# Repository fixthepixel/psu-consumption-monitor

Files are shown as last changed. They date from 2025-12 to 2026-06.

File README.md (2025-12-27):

# PSU Consumption Monitor

High-side current and power monitoring board for **ATX power supplies**.  
This project allows measuring real-time **current, voltage, and power consumption**
on major ATX rails for diagnostics, testing, and educational purposes.

Created and documented by **FixThePixel**.

---

## ✨ Features

- High-side current sensing using precision shunt resistors
- Multi-rail monitoring:
  - +12 V
  - +5 V
  - +3.3 V
  - +5 VSB
- Bus voltage and current measurement via **INA3221**
- Inline ATX connector design
- MicroPython-based firmware
- Project-local KiCad symbols and footprints
- Clean, GitHub-friendly project structure

---

## 📐 Measurements

Per-rail power is calculated as:

```
Power (W) = Voltage (V) × Current (A)
```

Total system power can be derived by summing all monitored rails.

---

## 🧰 Tools & Requirements

### Hardware / CAD

- **KiCad 9.x** (tested)
- Standard KiCad libraries (symbols, footprints, 3D models)

---

## 🧩 3D Models

This repository **does not include third-party 3D models**.

- Standard KiCad 3D models are referenced via `${KICAD*_3DMODEL_DIR}`
- Third-party 3D models shown in videos are **not bundled**
- Optional model links may be provided separately

---

## 🧪 Fabrication (Gerbers)

Generated Gerber files are included for **non-commercial manufacturing only**.

See `gerber/README.md` for fabrication-specific notes and licensing.

---

## 🔌 Firmware

The `/firmware` directory contains MicroPython firmware for the monitor.

### Firmware Installation Guide

1.  **Board**
   
    MicroPython firmware must be installed on the target board (RP2040).

2.  **Installation**
   
    Copy all `*.py` files from `/firmware` directory into the root directory of the MicroPython device.

3.  **Third-party dependencies**
   
    The firmware depends on the ILI9341 display driver and font files from:

    - `https://github.com/jeffmer/micropython-ili9341`

    Required files:
      - ili934xnew.py
      - glcdfont.py
      - tt14.py
      - tt24.py

    These files are used unmodified and retain their original MIT license.
    They must also be copied to the root directory of the MicroPython device.

---

## 📜 License

This project is licensed under:

**Creative Commons Attribution–NonCommercial 4.0 International (CC BY-NC 4.0)**

Commercial use, manufacturing, or sale is **not permitted** without explicit permission.

https://creativecommons.org/licenses/by-nc/4.0/

---

## ⚠️ Disclaimer

This project is intended for **development, diagnostics, and educational use**.

Working with ATX power supplies involves **high current and potentially hazardous voltages**.
Use at your own risk.

---

## 👤 Author

**FixThePixel**  
YouTube: https://www.youtube.com/@FixThePixel

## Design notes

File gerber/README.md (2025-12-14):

# Gerber Fabrication Files

This directory contains **generated Gerber files** for the
**PSU Consumption Monitor** PCB.

These files are provided for convenience to allow users to
manufacture the board without modifying the KiCad project.

---

## ⚠️ Important Notes

- The **KiCad schematic and PCB files** are the authoritative source.
- Gerber files are **derived artifacts** and may become outdated.
- Always review the files in a Gerber viewer before ordering PCBs.

---

## 📐 Board Information

- Layer count: 4
- Copper layers: F_Cu / In1_Cu / In2_Cu / B_Cu
- Separate drill files for PTH and NPTH
- Includes modern `.gbrjob` file

---

## 📜 License

These Gerber files are licensed under:

**Creative Commons Attribution–NonCommercial 4.0 International  
(CC BY-NC 4.0)**

### You MAY:
- Manufacture boards for **personal or educational use**
- Modify the design for **non-commercial purposes**
- Share the files with proper attribution

### You MAY NOT:
- Sell PCBs or assembled boards
- Manufacture for commercial purposes
- Use the design in commercial products
- Offer paid manufacturing or services using these files

Commercial use requires **explicit written permission**
from the author.

License text:
https://creativecommons.org/licenses/by-nc/4.0/

---

## 👤 Attribution

© 2025 **FixThePixel**

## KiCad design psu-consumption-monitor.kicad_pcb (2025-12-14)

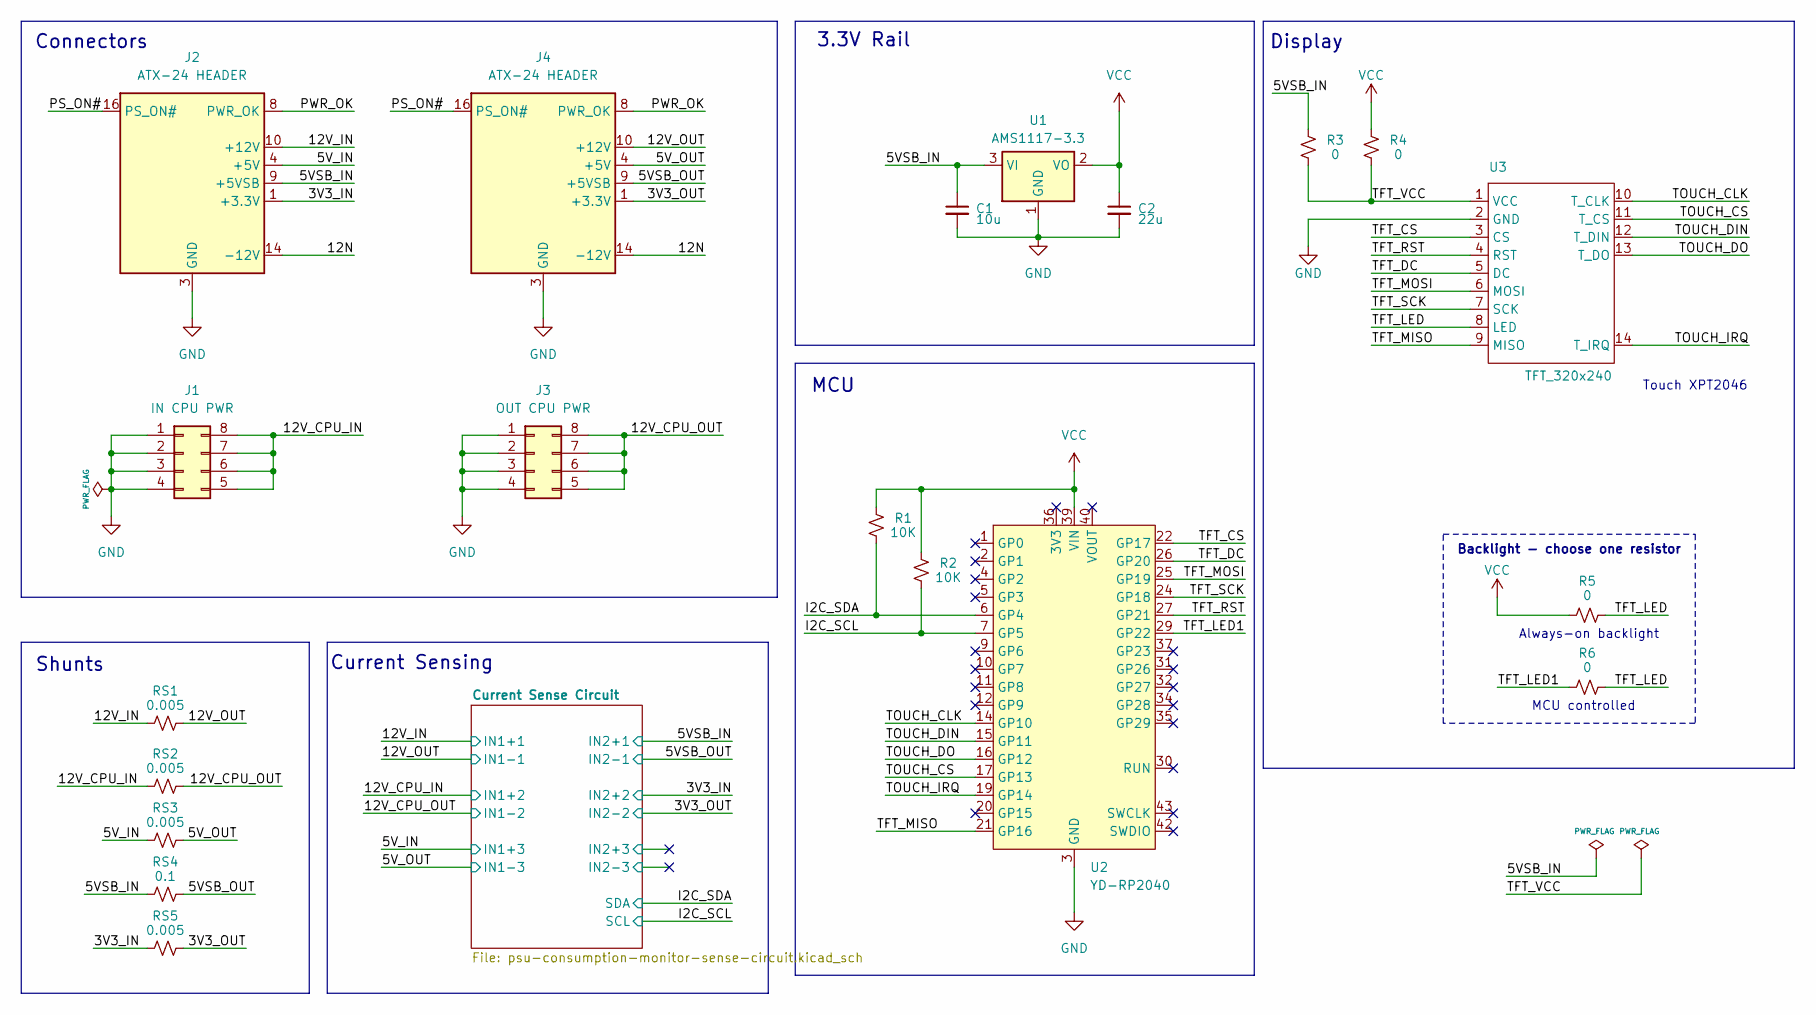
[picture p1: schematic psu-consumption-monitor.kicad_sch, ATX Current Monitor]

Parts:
C1: 10u; C_1206_3216Metric
C2: 22u; C_1206_3216Metric
J1: IN CPU PWR; Molex_Mini-Fit_Jr_5566-08A_2x04_P4.20mm_Vertical
J2, J4: ATX-24 HEADER; ATX-24-HEADER-HORIZONTAL
J3: OUT CPU PWR; Molex_Mini-Fit_Jr_5566-08A_2x04_P4.20mm_Vertical
R1, R2: 10K; R_0805_2012Metric
R3, R4, R5, R6: 0; R_0603_1608Metric
RS1, RS2, RS3, RS5: 0.005; R_2512_6332Metric
RS4: 0.1; R_2512_6332Metric
U1: AMS1117-3.3; SOT-223-3_TabPin2
U2: YD-RP2040
U3: TFT_320x240; TFT-320x240

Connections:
/3V3_IN: J2.1 (+3.3V), J2.2 (+3.3V), J2.12 (+3.3V), J2.13 (+3.3V), RS5.1; also elsewhere on the board
/3V3_OUT: J4.1 (+3.3V), J4.2 (+3.3V), J4.12 (+3.3V), J4.13 (+3.3V), RS5.2; also elsewhere on the board
/5VSB_IN: C1.1, J2.9 (+5VSB), R3.2, RS4.1, U1.3 (VI); also elsewhere on the board
/5VSB_OUT: J4.9 (+5VSB), RS4.2; also elsewhere on the board
/5V_IN: J2.4 (+5V), J2.6 (+5V), J2.21 (+5V), J2.22 (+5V), J2.23 (+5V), RS3.1; also elsewhere on the board
/5V_OUT: J4.4 (+5V), J4.6 (+5V), J4.21 (+5V), J4.22 (+5V), J4.23 (+5V), RS3.2; also elsewhere on the board
/12N: J2.14 (-12V), J4.14 (-12V)
/12V_CPU_IN: J1.5, J1.6, J1.7, J1.8, RS2.1; also elsewhere on the board
/12V_CPU_OUT: J3.5, J3.6, J3.7, J3.8, RS2.2; also elsewhere on the board
/12V_IN: J2.10 (+12V), J2.11 (+12V), RS1.1; also elsewhere on the board
/12V_OUT: J4.10 (+12V), J4.11 (+12V), RS1.2; also elsewhere on the board
/I2C_SCL: R2.1, U2.7 (GP5); also elsewhere on the board
/I2C_SDA: R1.1, U2.6 (GP4); also elsewhere on the board
/PS_ON#: J2.16 (PS_ON#), J4.16 (PS_ON#)
/PWR_OK: J2.8 (PWR_OK), J4.8 (PWR_OK)
/TFT_CS: U2.22 (GP17), U3.3 (CS)
/TFT_DC: U2.26 (GP20), U3.5 (DC)
/TFT_LED: R5.1, R6.1, U3.8 (LED)
/TFT_LED1: R6.2, U2.29 (GP22)
/TFT_MISO: U2.21 (GP16), U3.9 (MISO)
/TFT_MOSI: U2.25 (GP19), U3.6 (MOSI)
/TFT_RST: U2.27 (GP21), U3.4 (RST)
/TFT_SCK: U2.24 (GP18), U3.7 (SCK)
/TFT_VCC: R3.1, R4.1, U3.1 (VCC)
/TOUCH_CLK: U2.14 (GP10), U3.10 (T_CLK)
/TOUCH_CS: U2.17 (GP13), U3.11 (T_CS)
/TOUCH_DIN: U2.15 (GP11), U3.12 (T_DIN)
/TOUCH_DO: U2.16 (GP12), U3.13 (T_DO)
/TOUCH_IRQ: U2.19 (GP14), U3.14 (T_IRQ)
GND: C1.2, C2.2, J1.1, J1.2, J1.3, J1.4, J2.3 (GND), J2.5 (GND), J2.7 (GND), J2.15 (GND), J2.17 (GND), J2.18 (GND), J2.19 (GND), J2.24 (GND), J3.1, J3.2, J3.3, J3.4, J4.3 (GND), J4.5 (GND), J4.7 (GND), J4.15 (GND), J4.17 (GND), J4.18 (GND), J4.19 (GND), J4.24 (GND), U1.1 (GND), U2.3 (GND), U2.8 (GND), U2.13 (GND), U2.18 (GND), U2.23 (GND), U2.28 (GND), U2.33 (GND), U2.38 (GND), U2.44 (GND), U3.2 (GND); also elsewhere on the board
VCC: C2.1, R1.2, R2.2, R4.2, R5.2, U1.2 (VO), U2.39 (VIN); also elsewhere on the board

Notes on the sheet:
Current Sensing
Touch XPT2046
Shunts
3.3V Rail
Display
Backlight - choose one resistor
MCU controlled
Always-on backlight
Connectors
MCU

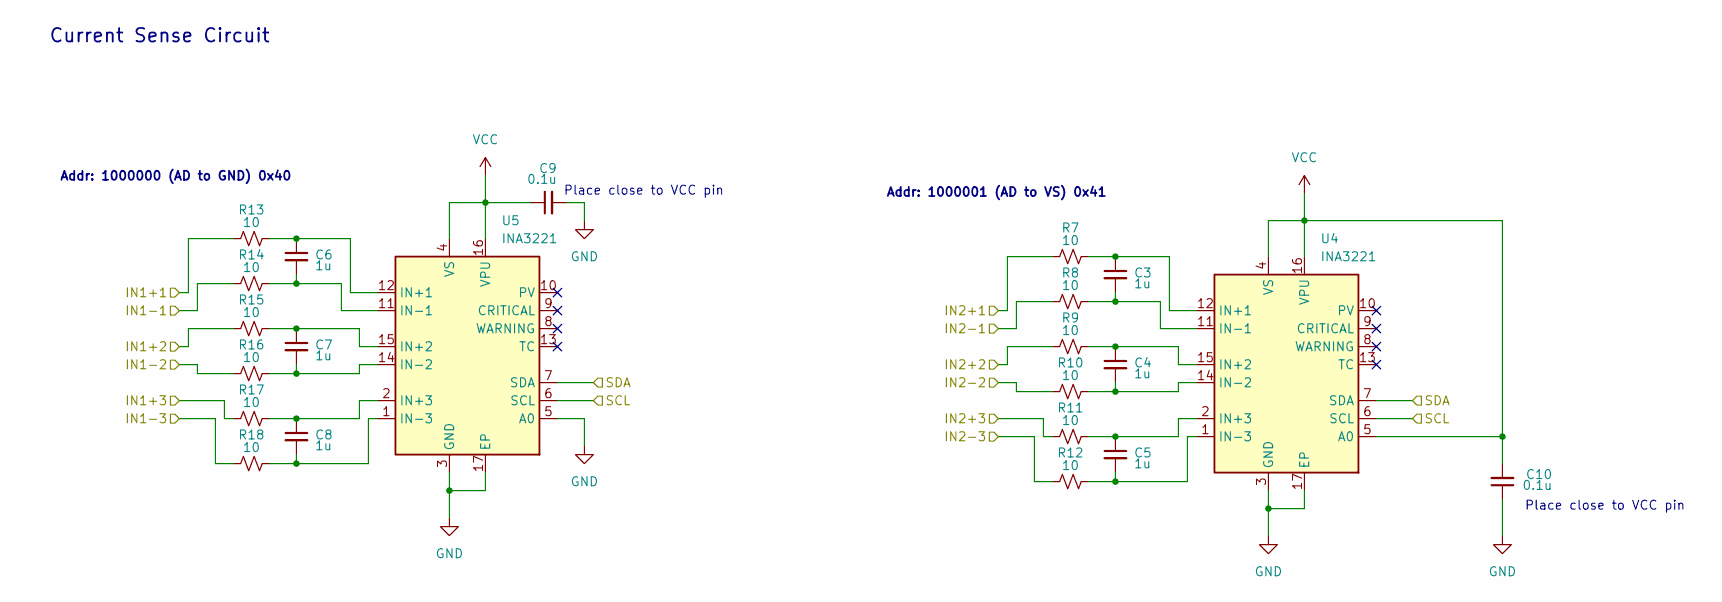
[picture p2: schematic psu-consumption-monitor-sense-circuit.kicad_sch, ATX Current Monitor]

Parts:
C3, C4, C5, C6, C7, C8: 1u; C_0603_1608Metric
C9, C10: 0.1u; C_0603_1608Metric
R7, R8, R9, R10, R11, R12, R13, R14, R15, R16, R17, R18: 10; R_0805_2012Metric
U4, U5: INA3221; Texas_RGV0016A_VQFN-16-1EP_4x4mm_P0.65mm_EP2.1x2.1mm

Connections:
/3V3_IN: R9.1; also elsewhere on the board
/3V3_OUT: R10.1; also elsewhere on the board
/5VSB_IN: R7.1; also elsewhere on the board
/5VSB_OUT: R8.1; also elsewhere on the board
/5V_IN: R17.1; also elsewhere on the board
/5V_OUT: R18.1; also elsewhere on the board
/12V_CPU_IN: R15.1; also elsewhere on the board
/12V_CPU_OUT: R16.1; also elsewhere on the board
/12V_IN: R13.1; also elsewhere on the board
/12V_OUT: R14.1; also elsewhere on the board
/Current Sense Circuit/IN2+3: R11.1
/Current Sense Circuit/IN2-3: R12.1
/I2C_SCL: U4.6 (SCL), U5.6 (SCL); also elsewhere on the board
/I2C_SDA: U4.7 (SDA), U5.7 (SDA); also elsewhere on the board
GND: C9.2, C10.1, U4.3 (GND), U4.17 (EP), U5.3 (GND), U5.5 (A0), U5.17 (EP); also elsewhere on the board
unnamed: C3.1, R7.2, U4.12 (IN+1)
unnamed: C4.1, R9.2, U4.15 (IN+2)
unnamed: C5.1, R11.2, U4.2 (IN+3)
unnamed: C3.2, R8.2, U4.11 (IN-1)
unnamed: C4.2, R10.2, U4.14 (IN-2)
unnamed: C5.2, R12.2, U4.1 (IN-3)
unnamed: C6.1, R13.2, U5.12 (IN+1)
unnamed: C7.1, R15.2, U5.15 (IN+2)
unnamed: C8.1, R17.2, U5.2 (IN+3)
unnamed: C6.2, R14.2, U5.11 (IN-1)
unnamed: C7.2, R16.2, U5.14 (IN-2)
unnamed: C8.2, R18.2, U5.1 (IN-3)
VCC: C9.1, C10.2, U4.4 (VS), U4.5 (A0), U4.16 (VPU), U5.4 (VS), U5.16 (VPU); also elsewhere on the board

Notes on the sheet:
Current Sense Circuit
Place close to VCC pin
Addr: 1000001 (AD to VS) 0x41
Addr: 1000000 (AD to GND) 0x40

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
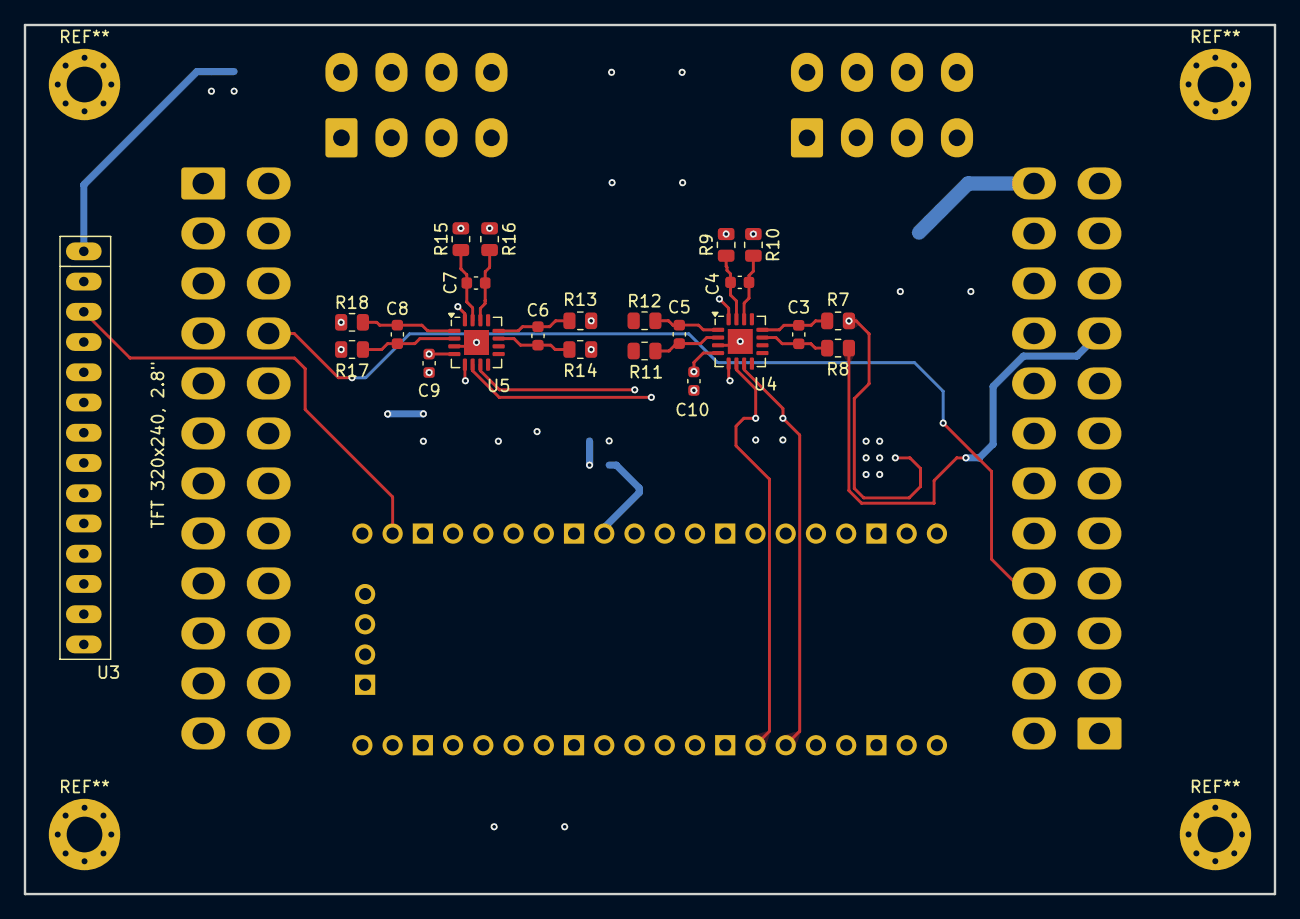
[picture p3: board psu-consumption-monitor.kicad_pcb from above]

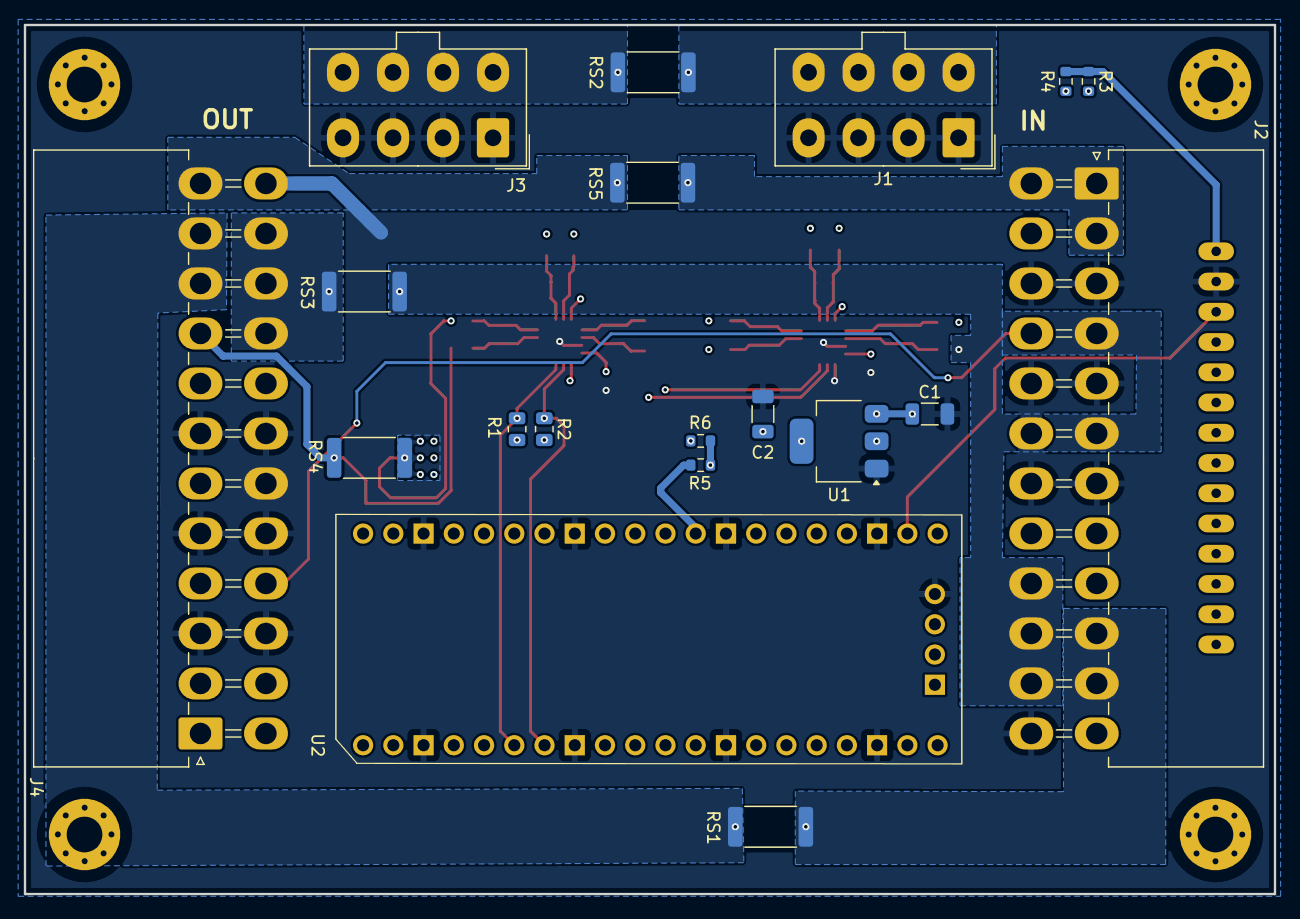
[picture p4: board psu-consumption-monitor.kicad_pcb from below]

Board: 4 copper layers, 105.0 x 73.0 mm, 42 parts (19 on the bottom side), 43 nets.

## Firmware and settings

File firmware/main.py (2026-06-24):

# main.py
from machine import Pin, I2C, SPI
import utime
import _thread
import ujson
from ina3221 import INA3221
from ili934xnew import ILI9341, color565
import tt14, tt24

# Parasitic resistances (vias and traces) in ohms
rp_shunt_12V     = 0.0035
rp_shunt_12V_CPU = 0.0000
rp_shunt_5V      = 0.0031
rp_shunt_3V      = 0.0017

# Shared sensor data protected by a lock
_data_lock = _thread.allocate_lock()
_shared = {
    "12v":     {"current": 0.0, "bus_voltage": 0.0, "power": 0.0},
    "12v_cpu": {"current": 0.0, "bus_voltage": 0.0, "power": 0.0},
    "5v":      {"current": 0.0, "bus_voltage": 0.0, "power": 0.0},
    "5vsb":    {"current": 0.0, "bus_voltage": 0.0, "power": 0.0},
    "3v3":     {"current": 0.0, "bus_voltage": 0.0, "power": 0.0},
    "total":   {"current": 0.0, "power": 0.0},
}

# Cache for storing text values based on coordinates and inversed flag
_text_cache = {}

# Graph ring buffers (320 samples, one per display column)
_GRAPH_Y     = 162
_GRAPH_H     = 35
_GRAPH_PMAX  = 300.0   # watts full scale
_GRAPH_IMAX  = 25.0    # amps full scale
_graph_power   = [0.0] * 320
_graph_current = [0.0] * 320
_graph_idx = 0

def _draw_graph_col(disp, col, power, current):
    disp.fill_rectangle(col, _GRAPH_Y, 1, _GRAPH_H, color565(0, 0, 0))
    ph = int(min(power / _GRAPH_PMAX, 1.0) * _GRAPH_H)
    if ph > 0:
        disp.fill_rectangle(col, _GRAPH_Y + _GRAPH_H - ph, 1, ph, color565(3, 161, 252))
    ch = int(min(current / _GRAPH_IMAX, 1.0) * (_GRAPH_H - 1))
    disp.pixel(col, _GRAPH_Y + _GRAPH_H - 1 - ch, color565(252, 215, 3))

def graph_update(disp, power, current):
    global _graph_idx
    _graph_power[_graph_idx] = power
    _graph_current[_graph_idx] = current
    _draw_graph_col(disp, _graph_idx, power, current)
    _graph_idx = (_graph_idx + 1) % 320
    disp.fill_rectangle(_graph_idx, _GRAPH_Y, 1, _GRAPH_H, color565(32, 32, 32))

def show_text(disp, x, y, text, inversed=False):
    key = (x, y, inversed)
    if _text_cache.get(key) == text:
        return
    if inversed:
        disp.set_color(color565(0, 0, 0), color565(255, 255, 255))
    disp.set_pos(x, y)
    disp.print(text)
    if inversed:
        disp.set_color(color565(255, 255, 255), color565(0, 0, 0))
    _text_cache[key] = text

# Core 1: poll sensors + send JSON every 200 ms
def serial_thread():
    while True:
        stamp = utime.ticks_ms()

        data1 = sensor1.read_all()
        data2 = sensor2.read_all()

        total_current = (data1[0]['current'] + data1[1]['current'] + data1[2]['current'] +
                         data2[0]['current'] + data2[1]['current'])
        total_power   = (data1[0]['power']   + data1[1]['power']   + data1[2]['power'] +
                         data2[0]['power']   + data2[1]['power'])

        _data_lock.acquire()
        try:
            _shared["12v"]     = dict(data1[0])
            _shared["12v_cpu"] = dict(data1[1])
            _shared["5v"]      = dict(data1[2])
            _shared["5vsb"]    = dict(data2[0])
            _shared["3v3"]     = dict(data2[1])
            _shared["total"]   = {"current": total_current, "power": total_power}
        finally:
            _data_lock.release()

        print(ujson.dumps({
            "12v":     dict(data1[0]),
            "12v_cpu": dict(data1[1]),
            "5v":      dict(data1[2]),
            "5vsb":    dict(data2[0]),
            "3v3":     dict(data2[1]),
            "total":   {"current": total_current, "power": total_power},
        }))

        elapsed = utime.ticks_diff(utime.ticks_ms(), stamp)
        delay = 200 - elapsed
        if delay > 0:
            utime.sleep_ms(delay)

print("ATX Current Monitor - Initializing...")

bl = Pin(22, Pin.OUT); bl.value(1)

spi = SPI(0, baudrate=40_000_000, polarity=0, phase=0, sck=Pin(18), mosi=Pin(19), miso=Pin(16))
print("ATX Current Monitor - SPI bus initialized")

disp = ILI9341(spi, dc=Pin(20), cs=Pin(17), rst=Pin(21), r=3, w=320, h=240)
print("ATX Current Monitor - Display initialized")

disp.erase()

# Static labels
disp.set_font(tt24)
disp.set_color(color565(255, 255, 255), color565(0, 0, 0))
show_text(disp, 2, 2,    "5V")
disp.set_font(tt14)
show_text(disp, 42, 10,  "VSB")
disp.set_font(tt24)
show_text(disp, 2, 32,   "12V ")
show_text(disp, 2, 52,   "5V")
show_text(disp, 2, 72,   "3.3V")
show_text(disp, 2, 102,  "12V")
disp.set_font(tt14)
show_text(disp, 42, 110, "CPU")
disp.set_font(tt24)
show_text(disp, 2, 132,  "TOTAL", True)
disp.set_font(tt14)
disp.set_color(color565(255, 255, 200), color565(0, 0, 0))
show_text(disp, 2, 220,  "PSU CONSUMPTION MONITOR")
disp.fill_rectangle(0, _GRAPH_Y - 1, 320, 1, color565(48, 48, 48))
disp.set_font(tt24)

i2c = I2C(0, scl=Pin(5), sda=Pin(4), freq=400_000)
print("ATX Current Monitor - I2C bus initialized")

sensor1 = INA3221(i2c, 0x40, [0.005 + rp_shunt_12V, 0.005 + rp_shunt_12V_CPU, 0.005 + rp_shunt_5V])
sensor2 = INA3221(i2c, 0x41, [0.1, 0.005 + rp_shunt_3V, 0.005])

print("ATX Current Monitor - INA3221 sensors initialized")

_thread.start_new_thread(serial_thread, ())

print("ATX Current Monitor - Initialized")

# Main loop (core 0): read shared data + update display
while True:
    stamp = utime.ticks_ms()

    _data_lock.acquire()
    try:
        d = {k: dict(v) for k, v in _shared.items()}
    finally:
        _data_lock.release()

    disp.set_font(tt24)

    disp.set_color(color565(252, 215, 3), color565(0, 0, 0))
    show_text(disp, 100, 2,   f"{d['5vsb']['current']:5.2f}A")
    show_text(disp, 100, 32,  f"{d['12v']['current']:5.2f}A")
    show_text(disp, 100, 52,  f"{d['5v']['current']:5.2f}A")
    show_text(disp, 100, 72,  f"{d['3v3']['current']:5.2f}A")
    show_text(disp, 100, 102, f"{d['12v_cpu']['current']:5.2f}A")

    disp.set_color(color565(252, 61, 3), color565(0, 0, 0))
    show_text(disp, 175, 2,   f"{d['5vsb']['bus_voltage']:04.1f}V")
    show_text(disp, 175, 32,  f"{d['12v']['bus_voltage']:04.1f}V")
    show_text(disp, 175, 52,  f"{d['5v']['bus_voltage']:04.1f}V")
    show_text(disp, 175, 72,  f"{d['3v3']['bus_voltage']:04.1f}V")
    show_text(disp, 175, 102, f"{d['12v_cpu']['bus_voltage']:04.1f}V")

    disp.set_color(color565(3, 161, 252), color565(0, 0, 0))
    show_text(disp, 250, 2,   f"{d['5vsb']['power']:5.1f}W")
    show_text(disp, 250, 32,  f"{d['12v']['power']:5.1f}W")
    show_text(disp, 250, 52,  f"{d['5v']['power']:5.1f}W")
    show_text(disp, 250, 72,  f"{d['3v3']['power']:5.1f}W")
    show_text(disp, 250, 102, f"{d['12v_cpu']['power']:5.1f}W")

    show_text(disp, 100, 132, f"{d['total']['current']:5.2f}A", True)
    show_text(disp, 250, 132, f"{d['total']['power']:5.1f}W",   True)

    graph_update(disp, d['total']['power'], d['total']['current'])

    display_show_ms = utime.ticks_diff(utime.ticks_ms(), stamp)

    disp.set_font(tt14)
    disp.set_color(color565(255, 255, 200), color565(0, 0, 0))
    show_text(disp, 2, 200, f"D: {display_show_ms:04d}")

    loop_delay = 500 - display_show_ms
    if loop_delay < 50:
        loop_delay = 50
    utime.sleep_ms(loop_delay)

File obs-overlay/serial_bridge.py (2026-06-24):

#!/usr/bin/env python3
"""
RP2040 JSON Serial → HTTP bridge for OBS Browser Source

Usage:
  Linux/Mac:  python serial_bridge.py --port /dev/ttyACM0
  Windows:    python serial_bridge.py --port COM3

Install dependency first:
  pip install pyserial
"""

import argparse
import json
import threading
import time
from http.server import BaseHTTPRequestHandler, HTTPServer

import serial

# ── Shared state ──────────────────────────────────────────────────────────────
latest = {}
lock = threading.Lock()

# ── Serial reader thread ──────────────────────────────────────────────────────
def serial_reader(port: str, baud: int):
    while True:
        try:
            print(f"[serial] Connecting to {port} @ {baud}...")
            with serial.Serial(port, baud, timeout=2) as ser:
                print(f"[serial] Connected.")
                while True:
                    raw = ser.readline().decode("utf-8", errors="ignore").strip()
                    if not raw:
                        continue
                    try:
                        parsed = json.loads(raw)
                        with lock:
                            latest.clear()
                            latest.update(parsed)
                    except json.JSONDecodeError:
                        print(f"[serial] Bad JSON: {raw!r}")
        except serial.SerialException as e:
            print(f"[serial] Error: {e}  — retrying in 3s")
            time.sleep(3)

# ── HTTP server ───────────────────────────────────────────────────────────────
class Handler(BaseHTTPRequestHandler):
    def do_GET(self):
        if self.path == "/data":
            with lock:
                body = json.dumps(latest).encode()
            self.send_response(200)
            self.send_header("Content-Type", "application/json")
            self.send_header("Access-Control-Allow-Origin", "*")
            self.send_header("Cache-Control", "no-cache")
            self.end_headers()
            self.wfile.write(body)
        else:
            self.send_response(404)
            self.end_headers()

    def log_message(self, *_):  # silence request logs
        pass

# ── Main ──────────────────────────────────────────────────────────────────────
def main():
    ap = argparse.ArgumentParser(description="RP2040 serial → HTTP bridge for OBS")
    ap.add_argument("--port",      default="/dev/ttyACM0", help="Serial port (e.g. COM3 or /dev/ttyACM0)")
    ap.add_argument("--baud",      type=int, default=115200, help="Baud rate (default: 115200)")
    ap.add_argument("--http-port", type=int, default=5757,   help="Local HTTP port (default: 5757)")
    args = ap.parse_args()

    t = threading.Thread(target=serial_reader, args=(args.port, args.baud), daemon=True)
    t.start()

    server = HTTPServer(("127.0.0.1", args.http_port), Handler)
    print(f"[http]  Serving at http://127.0.0.1:{args.http_port}/data")
    print(f"[http]  Press Ctrl+C to stop.")
    server.serve_forever()

if __name__ == "__main__":
    main()
